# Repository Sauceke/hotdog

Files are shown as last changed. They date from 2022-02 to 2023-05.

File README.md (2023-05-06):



# Hotdog

*A pocket pussy with depth sensing.*

<br>

<div align = center>

---

[][Demo]   
[][Firmware]   
[][PCB & Case]

---

</div>

<br>
<br>

## Assembly

*How to build this project.*

[][Wireless]   
[][Wired]

<br>
<br>

## Acknowledgment

Thanks to **[@ManlyMarco]** for the idea.

<br>

<!----------------------------------------------------------------------------->

[@ManlyMarco]: https://github.com/ManlyMarco
[Demo]: https://www.erome.com/a/rvRyi8gS

[License]: LICENSE
[PCB & Case]: https://github.com/Sauceke/hotdog/tree/master/Source/Hardware
[Firmware]: https://github.com/Sauceke/hotdog/tree/master/Source/Firmware
[Wireless]: Documentation/Wireless.md
[Wired]: Documentation/Wired.md

<!---------------------------------[ Badges ]---------------------------------->

[Badge License]: https://img.shields.io/badge/License-GPL_3-blue.svg?style=for-the-badge

<!--------------------------------[ Buttons ]---------------------------------->

[Button PCB & Case]: https://img.shields.io/badge/PCB_&_Case-3863A0?style=for-the-badge&logoColor=white&logo=Task
[Button Firmware]: https://img.shields.io/badge/Firmware-00979D?style=for-the-badge&logoColor=white&logo=Arduino
[Button Wireless]: https://img.shields.io/badge/Wireless-006643?style=for-the-badge&logoColor=white&logo=RSS
[Button Wired]: https://img.shields.io/badge/Wired-2D50A5?style=for-the-badge&logoColor=white&logo=EquinixMetal
[Button Demo]: https://img.shields.io/badge/NSFW_Demo-ED2761?style=for-the-badge&logoColor=white&logo=Aparat

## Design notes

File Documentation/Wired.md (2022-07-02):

# Wired Assembly

*How to build a cheap **Hotdog**.*

<br>

If you have access to a 3D printer and use a cheap  
Nano clone with `CH340`, the whole thing will run  
you around `$20`, not counting the sleeve itself.

<br>

## Parts

-   Transparent Sleeve

    *I use **[This][Sleeve]** one.*

-   3D Printed

    - **[Bottom Casing]**
    - **[Top Casing]**
    
    <br>
    
-   Arduino Nano

-   2 x Single row 15 pin female header

-   2 x Universal PCB 

    `50mm x 100mm`
    
    Such as:
    
    - **[Amazon][PCB Amazon]**
    - **[Hestore][PCB Hestore]**
    - **[Ormix][PCB Ormix]**
    
    <br>
    
-   5 x `GL5528` Photoresistor

-   3 x `334-15/T1C1-4WYA` LEDs 
    
    *These are actually overkill, you could also*  
    *go with dimmer LEDs and a smaller resistor*
    
-   `1kΩ` resistor

-   Long USB cable 

    *For the Arduino Nano*

-   Mini zip ties

    *Less than `3mm` in width*
    
-   Rubber bands

-   Solder and hook-up wire

<br>
<br>

## Programming

Upload the **[Firmware]** to the micro-controller.

*Check out the **[Guide]** if you have never done this.*

<br>
<br>

## Assembly

1.  Place the photo-resistors on the **back side** of the  
    PCB at equal distances along the middle line.

    The exact distance between them is not that  
    important, but try to place them evenly.
    
    Solder them in position.
    
    *This is easier if your PCB is plated on both sides, if it  
    isn't, then take extra care not to burn the photocells.*

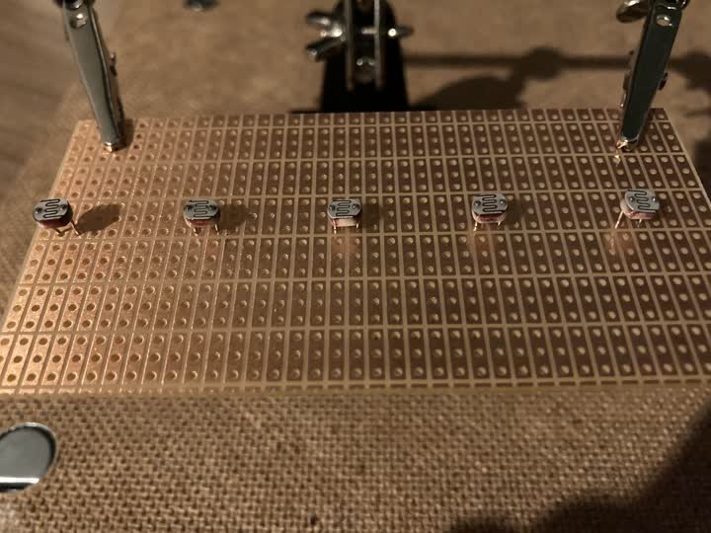
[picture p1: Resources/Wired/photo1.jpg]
    
    
    <br>

2.  Wire up the photocells as shown diagram, except  
    with the wires on the **front side** of the board.
    
    

    The front side should look something like this:
    
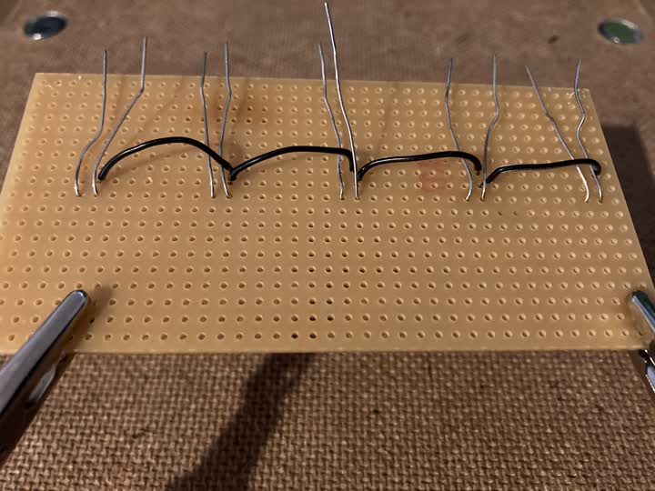
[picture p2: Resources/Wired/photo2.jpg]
    
    
    <br>

3.  Put the sockets on the Nano and solder them  
    onto the board in the below orientation.

    *Leave at least one row space at the top ↓*

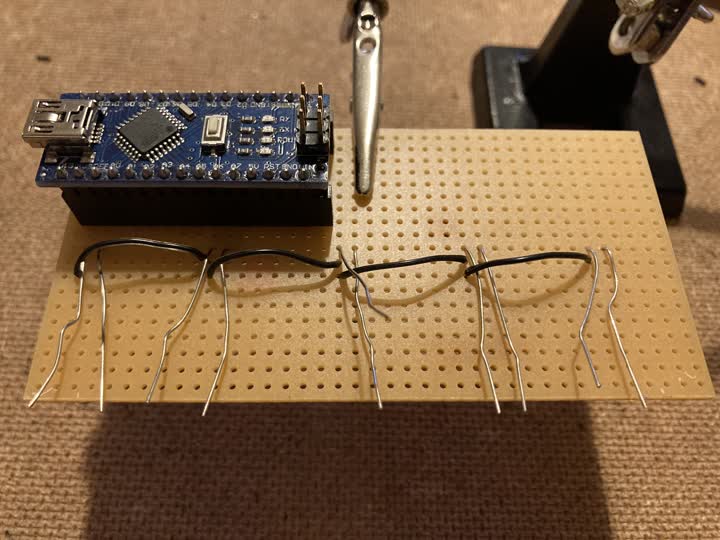
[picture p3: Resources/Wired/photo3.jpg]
    

    You don't have to solder each and every pin  
    in, but at the bare minimum, do the corners.
    
    Make sure you don't solder any adjacent pins together.
    
    <br>

4.  Now connect the photocells to the  
    Nano according to the diagram.

    ***Do NOT solder the wires directly onto***  
    ***the Nano, solder them to the sockets.***
    
    *I couldn't find a way to illustrate this in*  
    *Fritzing, so also see the photo for reference.*

    
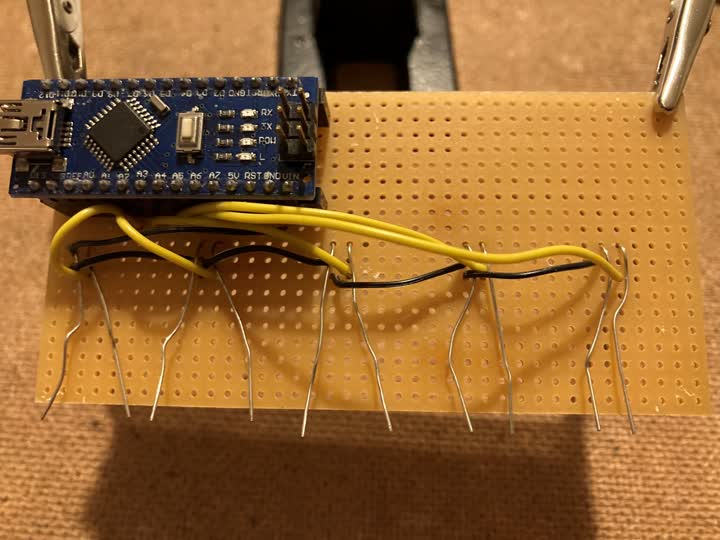
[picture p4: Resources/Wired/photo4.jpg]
    

    After the photocells are connected, you can trim off all the legs.
    
    <br>

5.  Mount the LEDs on the second PCB and  
hook them up to the Nano to each other.
    
    *Black wire to cathodes.*

    Don't forget the resistor.
    
    
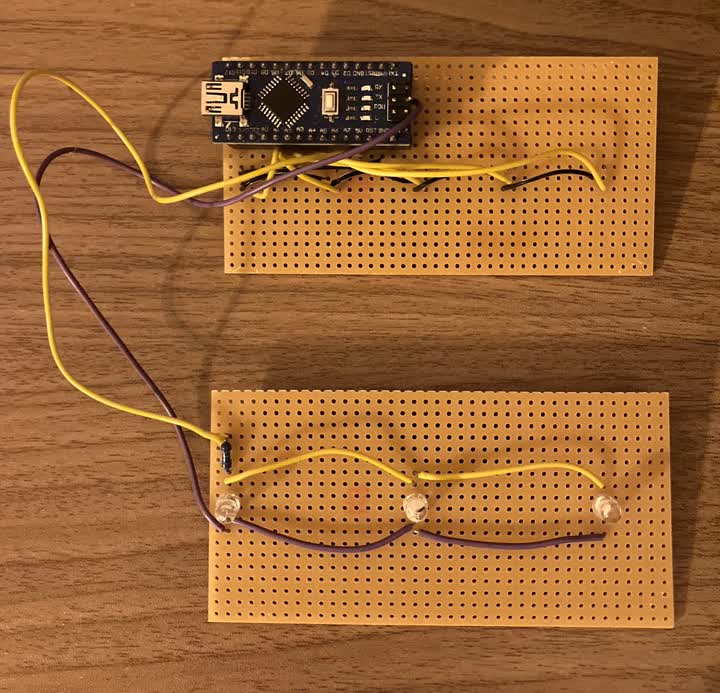
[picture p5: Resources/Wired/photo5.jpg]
    

    <br>

6.  Tie the casings together at the back with zip-ties.

    Leave them loose and don't tighten them until the sleeve is in.

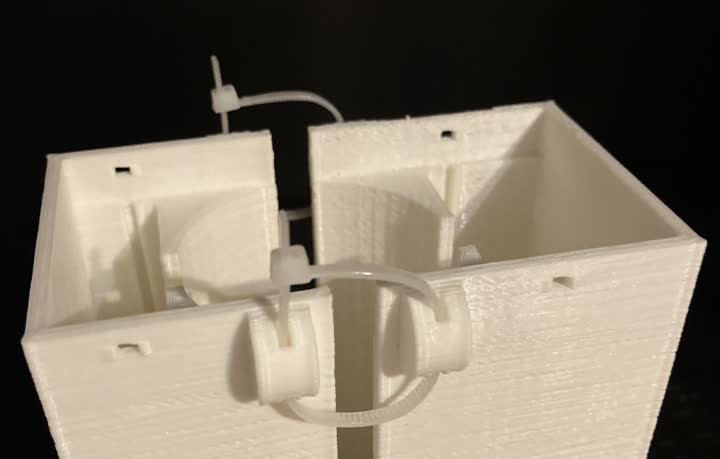
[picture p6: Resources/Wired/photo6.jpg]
    

    <br>

7.  Slide the PCBs in, secure each with a zip-tie  
    and the clipped off end of another zip-tie.
    
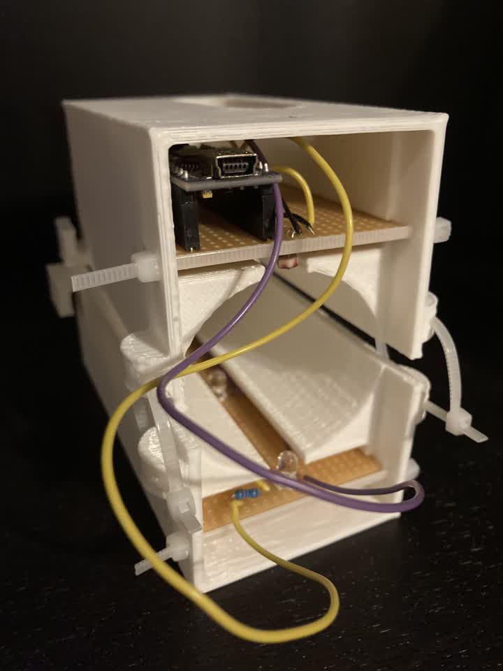
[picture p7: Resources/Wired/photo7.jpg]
    
    
    <br>

8.  Add the sleeve, hold it down with rubber bands  
    at the front and tighten the zip-ties at the back.

    *Make sure all sides of the casing press down on the sleeve evenly.*

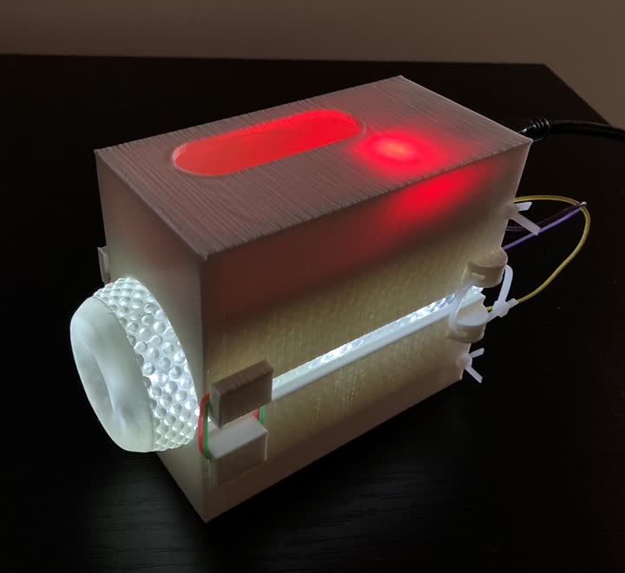
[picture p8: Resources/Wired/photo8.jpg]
    

    <br>

9.  Serve hot.

<br>

<!----------------------------------------------------------------------------->

[Firmware]: https://github.com/Sauceke/hotdog/releases/latest/download/hotdog-fw.ino

[Guide]: https://docs.arduino.cc/software/ide-v1/tutorials/getting-started/cores/arduino-avr

<!---------------------------------[ Parts ]----------------------------------->

[Sleeve]: https://www.thehandy.com/product/the-handy-open-ended-sleeve-collection-hard-eu-uk-2/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

[Bottom Casing]: https://github.com/Sauceke/hotdog/releases/latest/download/hotdog-case-bottom.stl
[Top Casing]: https://github.com/Sauceke/hotdog/releases/latest/download/hotdog-case-top.stl

[PCB Hestore]: https://www.hestore.hu/prod_10031793.html?lang=en
[PCB Amazon]: https://www.amazon.de/-/en/WITTKOWARE-Perforated-Compartments-Copper-RM2-54/dp/B07W8H39TR
[PCB Ormix]: https://ormix.lv/en/catalog/item/id/21692/

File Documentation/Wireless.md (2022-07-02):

# Wireless Assembly

*How to build an **IOT Hotdog**.*

<br>

## Parts list

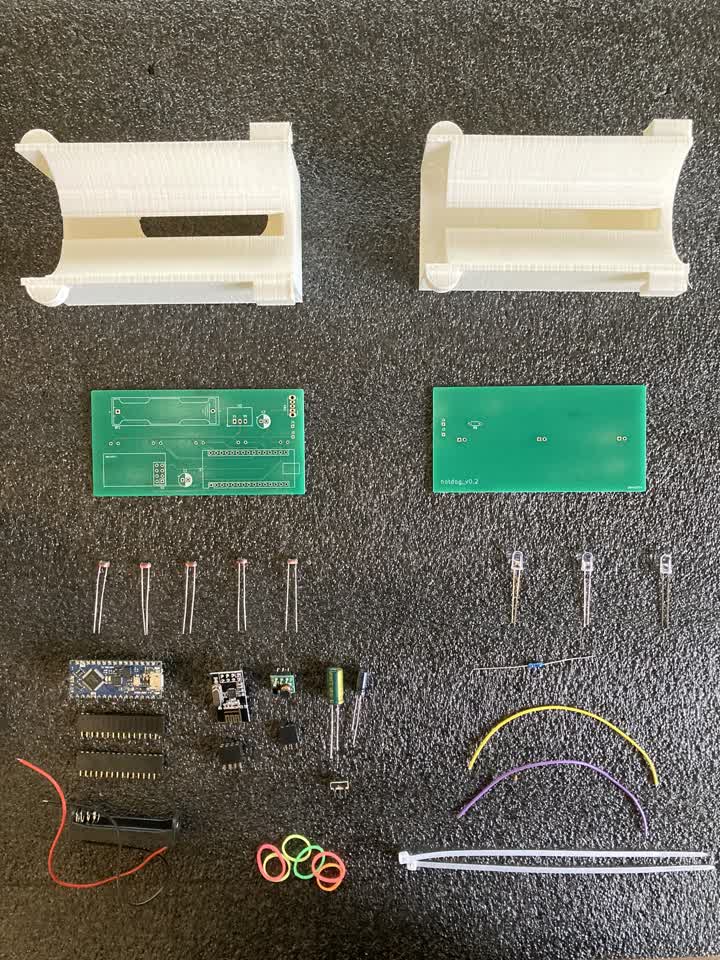
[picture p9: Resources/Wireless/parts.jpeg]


<br>

### Custom Parts

#### 3D Print

- **[Top Casing]**

- **[Bottom Casing]**

<br>

#### Order PCBs

Estimated Cost : `10 - 20 US$` per PCB

- **[Front PCB]**

- **[Back PCB]**

###### Specifications:

- Solder Mask : `Yes`
- Thickness : `1.6mm`
- Layers: `2`
- Size : `100 x 50 mm`
- HASL : `Yes`

<br>

### Stock Parts

- **`A1` : Arduino Nano or compatible + two `1x15` pin female headers**

- `BT1` : AAA battery holder (thru-hole mount recommended)

- `C1` : `10 - 100uF` capacitor (optional)

- `C2` : `~1000uF` capacitor (optional)

- **`D1-D3` : three white LEDs, I used `334-15` / `T1C1-4WYA`**

- **`12cm` long hook-up wire connecting `J1` to `J4`**

- **`12cm` long hook-up wire connecting `J2` to `J3`**

- **`R1-R5` : five GL5528 photoresistors**

- **`R6` : 1kΩ resistor (or lower if you're using less bright LEDs)**

- `SW1` : **SPDT** switch

- `U1` : `nRF24L01` + a `2x4` pin female header

- `U2` : `0.8 - 5V` to `5V` boost converter + a `1x3` pin female header

- A transparent sleeve, I used **[This][Sleeve]** one.

- Mini zip ties

- Rubber bands

<br>
<br>

## Programming

### Arduino Nano

Extract this **[Zip]** file and upload  
the file `hotdog-fw.ino.hex` to  
the Nano using **[XLoader]**.

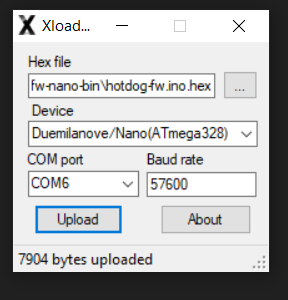
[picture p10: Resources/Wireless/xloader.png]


##### Windows

By default you should be able to  
use `COM0`, if not try other ports.

<br>

### Other 

*Nano-compatible microcontrollers*

Compile & upload the **[Firmware]** using the **[Arduino IDE]**.

##### Dependencies

- **Protothreads**
- **BTLE**
- **RF24**

<br>
<br>

## Assembly

### Soldering Font PCB

1.  Place the `1x15` headers on the Nano.

    *I didn't have 1x15, so I cheated and yanked*  
    *out one of the terminals from a `1x16`.*
    
    *Don't be like me.*

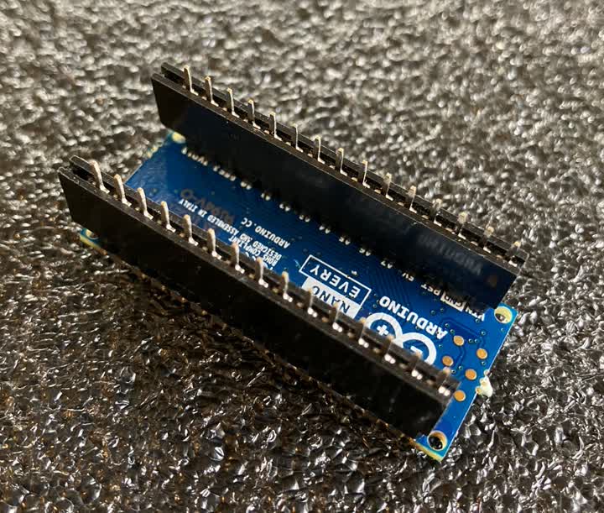
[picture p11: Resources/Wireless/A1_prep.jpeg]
    
    
    <br>

2.  Solder the micro-controller to the PCB with  
    its USB connector facing towards the edge.

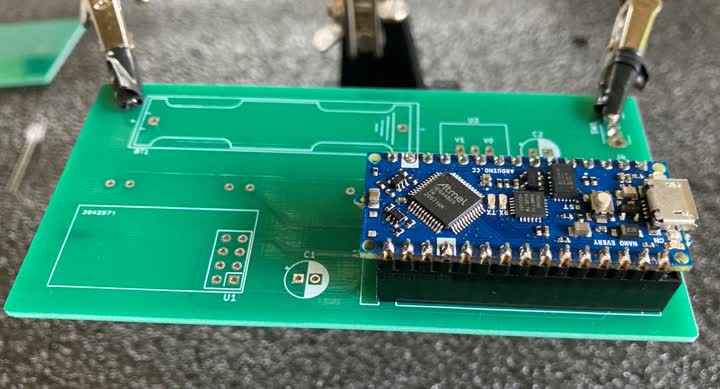
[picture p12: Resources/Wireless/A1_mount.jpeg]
    
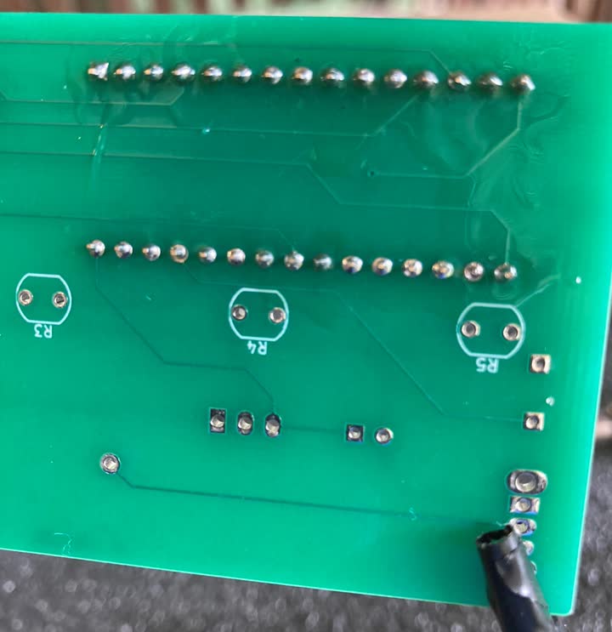
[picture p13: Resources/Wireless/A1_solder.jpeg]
    
    
    <br>

3.  Solder the photo-resistors to `R1-R5`  
    on the opposite side of the PCB.

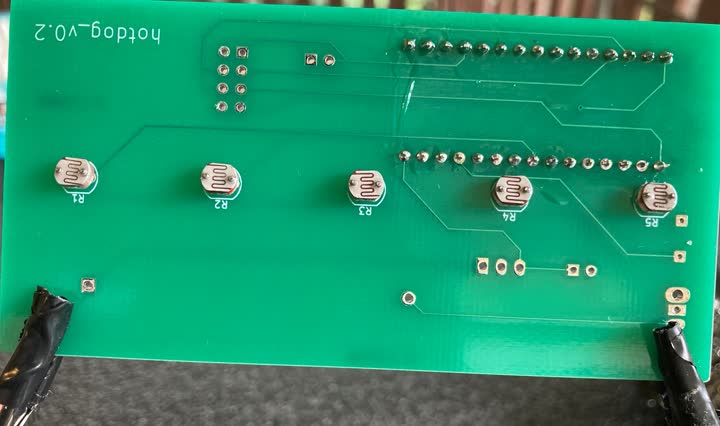
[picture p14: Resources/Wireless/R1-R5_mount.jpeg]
    

    <br>

    *It is recommended to clip the leads off*  
    *before soldering to minimize heat loss.*
    
    I prefer to also bend the wires in before clipping  
    them short, so the parts won't come loose.

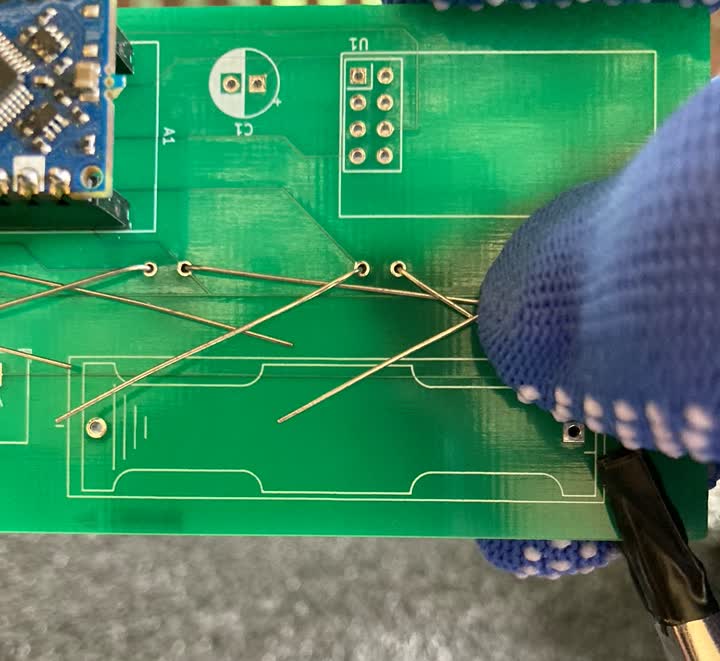
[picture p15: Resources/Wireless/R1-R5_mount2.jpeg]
    
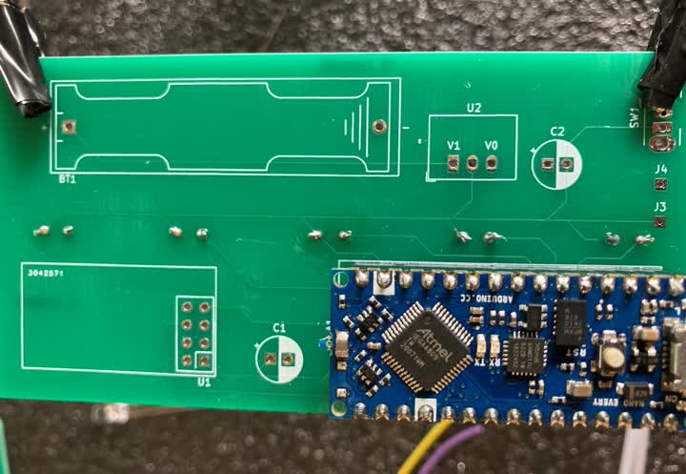
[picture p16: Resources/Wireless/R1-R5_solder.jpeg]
    
    
    <br>

4.  Solder the `2x4` header to `U1`.

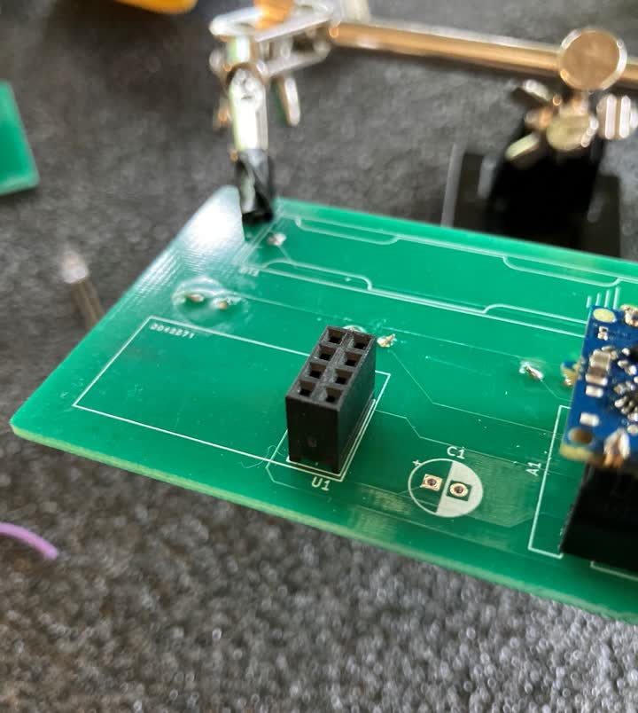
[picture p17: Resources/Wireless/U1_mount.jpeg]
    
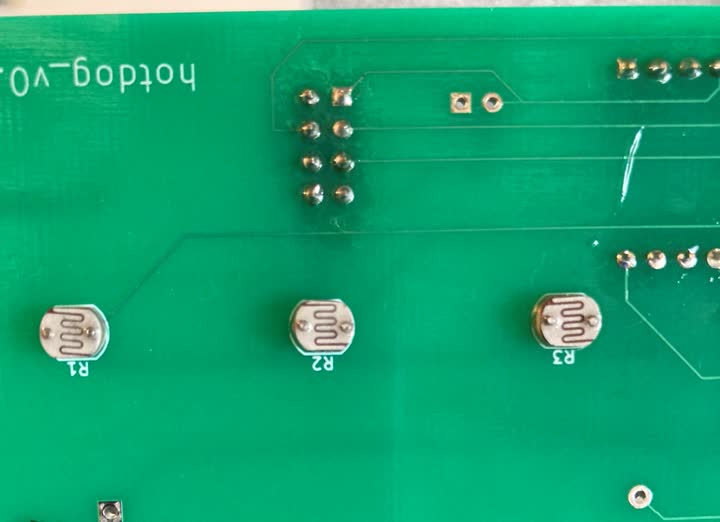
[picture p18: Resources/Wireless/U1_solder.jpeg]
    
    
    <br>

5.  Put the `1x3` female header on the  
    boost converter and solder it to `U2`.

    Make sure `V1` and `V0` are aligned  
    with the markings on the PCB.

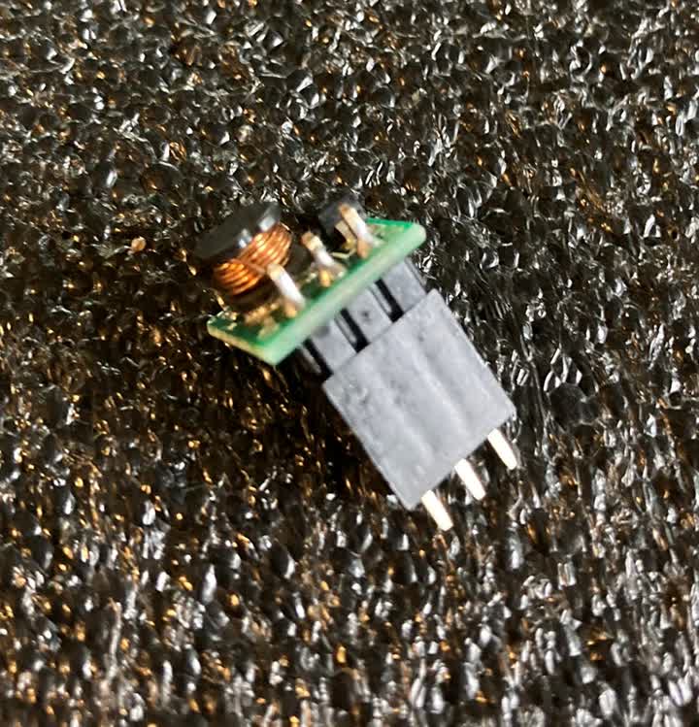
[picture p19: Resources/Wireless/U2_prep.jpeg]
    
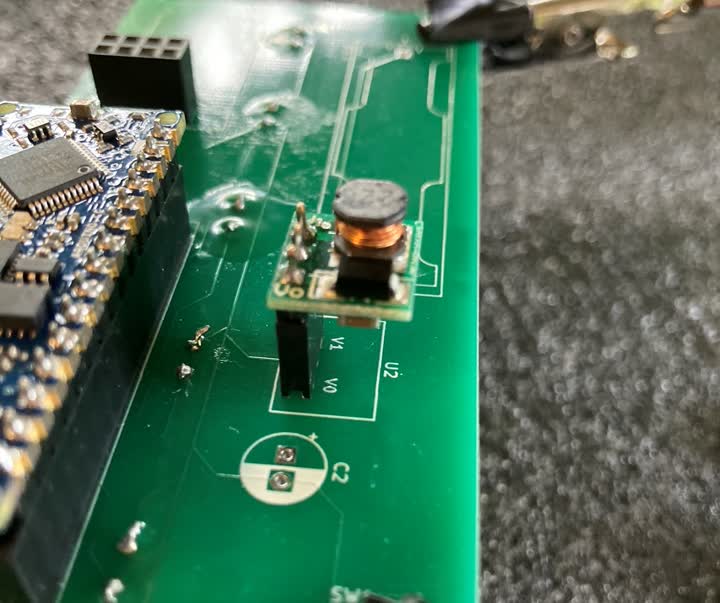
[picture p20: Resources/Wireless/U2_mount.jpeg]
    
    
    <br>

6.  Solder a capacitor of about `1000uF` to `C2`.

    ***Mind the polarity.***

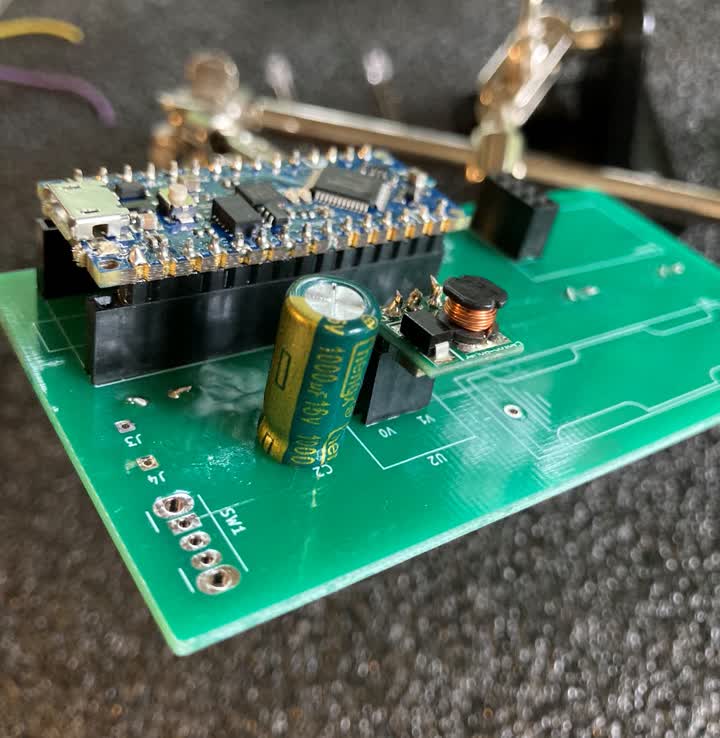
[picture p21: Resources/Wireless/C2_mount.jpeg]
    
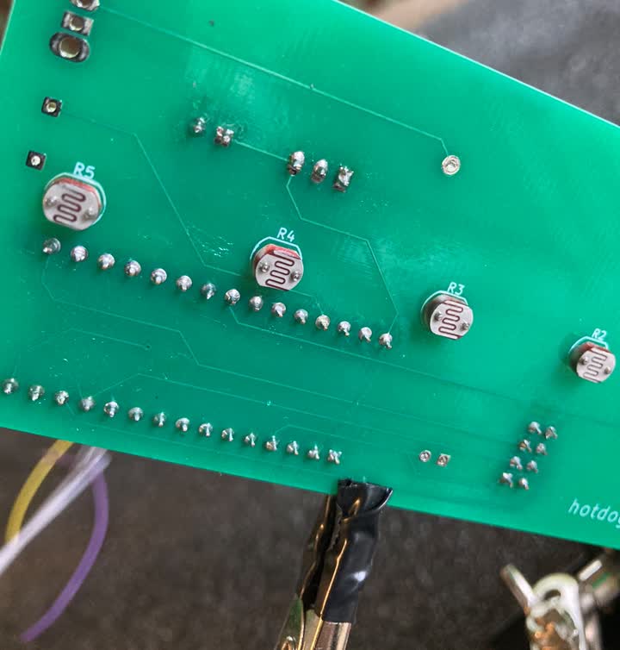
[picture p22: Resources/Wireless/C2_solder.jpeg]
    
    
    <br>

7.  Solder the **SPDT** switch to `SW1`.

    The terminals should go into the three holes in the middle.
    
    Mine was a bit over-sized, but as they  
    say, if there's a hole, there's a way.

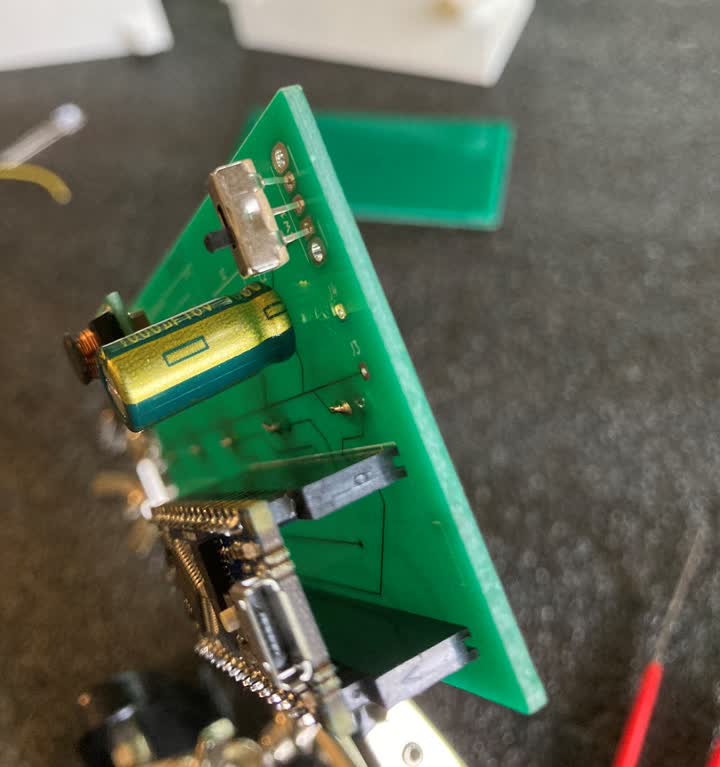
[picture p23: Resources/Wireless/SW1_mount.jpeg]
    
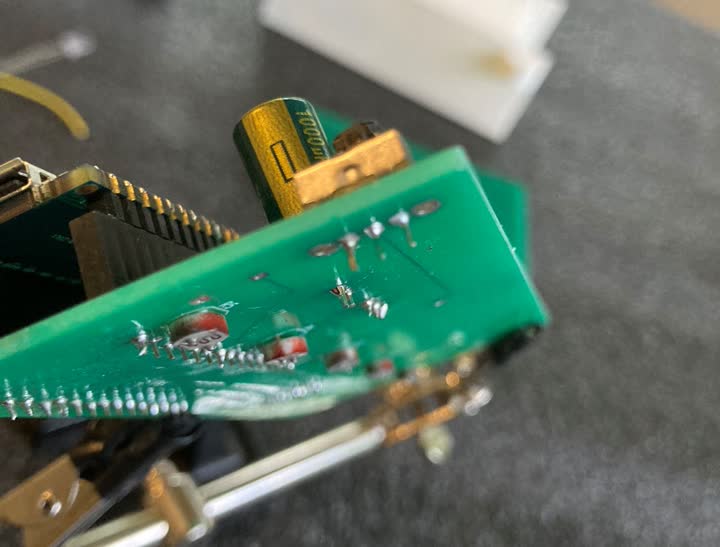
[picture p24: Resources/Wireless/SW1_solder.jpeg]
    

    Words to live by indeed.
    
    <br>

8.  If you have a thru-hole mount `1xAAA` battery  
    holder, you can go ahead and solder it to `BT1`  
    and skip to step 13.

    ***Mind the polarity***

    If you're using a cheaper battery holder like  
    I did, we need to take a few extra steps.
    
    This can get quite messy though, so in  
    retrospect I absolutely recommend  
    getting a proper thru-hole mount.
    
    <br>

9.  First, trim both wires to about `2cm`, and put some  
    deep scratches into the bottom with a sharp object.

    This is crucial to ensure proper adhesion  
    to the board, so carve it up like a psycho.

    
    
    <br>

10. Then solder it to `BT1` in the correct polarity.

    
    
    <br>

11. Clean both the `BT1` footprint and the  
    battery holder with isopropyl alcohol.

12. Glue the battery holder to `BT1` with epoxy.

    ***⚠ Make sure there is at least `5mm` clearance***  
    ***between the battery holder and the edge of***  
    ***the motherboard.***
    
    *It doesn't have to be precisely on the footprint,*  
    *but do not place it any further below that.*

    
    

    Clamp it down and wait for the glue to dry.
    
    Meanwhile, you can start assembling the [Back PCB](#soldering-back-pcb).
    
    <br>

13. Solder a 100uF capacitor to `C1`.

    ***Mind the polarity.***

    
    
    <br>

14. Insert the `nRF24` into the `U1` socket,  
    and that's the front motherboard done.

    
    

<br>
<br>

### Soldering Back PCB

1.  Solder the LEDs to `D1-D3`.

    Pay attention to polarity; one of the sides  
    on each LED is flattened, line that up with  
    the drawing on the PCB.
      
    
    
    
    <br>
  
2.  Solder a `1K` resistor to `R6`.

    
    
    <br>

3.  Connect `J1` to `J4` and `J2` to `J3`  
    with `12cm` long hook-up wires.

    Solder those in as well.

    

    The motherboards are now complete.

    

<br>
<br>

### Final Assembly

1.  Slide the PCB into the casing:

    **Front PCB**  ➞  **Top Casing**

    **Bottom PCB**  ➞  **Bottom Casing**

    *Make sure the LEDs and the photo-resistors*  
    *all face inwards, where the sleeve will be.*

2.  Secure each PCB with a zip tie and  
    the cut-off end of another zip tie.

3.  Add the sleeve.

4.  Use zip ties to bind the two casing  
    parts at their open ends together.

    Fasten the zip ties just tight enough that  
    the casing won't separate from the sleeve.

5.  Secure the other end of the casing  
    to the sleeve with rubber bands.

6.  Insert the battery, power it on and serve.

<br>
<br>

## Operation

In wireless mode, the **Hotdog** is powered by a single  
AAA battery that should last you about `2 - 3` hours  
on a single charge.

*I recommend using a rechargeable one.*

*There's no battery level indicator, so recharge frequently.*

I'm still working on the client app for  
wireless, but it's already looking great.

Stay tuned!

<br>

<!----------------------------------------------------------------------------->

[Firmware]: https://github.com/Sauceke/hotdog/releases/latest/download/hotdog-fw.ino
[Zip]: https://github.com/Sauceke/hotdog/releases/latest/download/hotdog-fw-nano-bin.zip

[Arduino IDE]: https://www.arduino.cc/en/software
[XLoader]: https://www.hobbytronics.co.uk/arduino-xloader

<!---------------------------------[ Parts ]----------------------------------->

[Bottom Casing]: https://github.com/Sauceke/hotdog/releases/latest/download/hotdog-case-bottom.stl
[Top Casing]: https://github.com/Sauceke/hotdog/releases/latest/download/hotdog-case-top.stl

[Front PCB]: https://github.com/Sauceke/hotdog/releases/latest/download/hotdog-pcb-front-fab.zip
[Back PCB]: https://github.com/Sauceke/hotdog/releases/latest/download/hotdog-pcb-back-fab.zip

[Sleeve]: https://www.thehandy.com/product/the-handy-open-ended-sleeve-collection-hard-eu-uk-2/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

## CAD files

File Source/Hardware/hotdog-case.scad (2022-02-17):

$fn = 50;

t = 0.7; // tolerance
pcb = [50 + t, 1.5 + t, 100 + t];

big = 420; // arbitrary big value

module pcb_clearance(h_top) {
    h_bottom = 5;
    h_slit = 30;
    w_slit = 10;
    margin = 4;
    cube(pcb, center = true);
    translate([0, -h_top / 2, 0])
        cube([pcb[0] - margin, h_top, pcb[2] - margin], center = true);
    translate([0, h_bottom / 2, 0])
        cube([pcb[0] - margin, h_bottom, pcb[2] - margin], center = true);
    translate([0, h_slit / 2, 0])
        cube([w_slit, h_slit, pcb[2]], center = true);
    translate([0, -h_top / 2, pcb[2] / 2])
        cube([pcb[0], h_top, 10], center = true);
    translate([0, big / 2, pcb[2] / 2])
        cube([pcb[0], big, 10], center = true);
    translate([0, 0, pcb[2] / 2 + 1])
        cube([big, 3, 2], center = true);
}

module sleeve_clearance() {
    sleeve_d = 50;
    translate([0, 32, 0])
    cylinder(d = sleeve_d, h = pcb[2] + 20, center = true);
}

module ear() {
    ear_h = 15;
    intersection() {
        difference() {
            cube([8, 8, ear_h], center = true);
            cube([3, 2, ear_h], center = true);
        }
        translate([4, 0, 0])
            rotate([90, 0, 0])
                cylinder(d = ear_h, h = 100, center = true);
    }
}

module hook() {
    ear_h = 16;
        difference() {
            cube([8, 12, ear_h], center = true);
            translate([2, -2, 0])
                cube([4, 8, big], center = true);
        }
}

module case(h_top, battery_hole) {
    difference() {
        translate([0, (25 - h_top) / 2, 0])
            cube([pcb[0] + 5, 30 + h_top, pcb[2] + 10], center = true);
        pcb_clearance(h_top);
        sleeve_clearance();
        if (battery_hole) {
            hull() {
                rotate([90, 0, 0]) {
                    translate([-10, -pcb[2] / 2 + 20, 0])
                        cylinder(d = 20, h = big);
                    translate([-10, 10, 0])
                        cylinder(d = 20, h = big);
                }
            }
        }
    }
    corner = [- pcb[0] / 2 - 6, 20, pcb[2] / 2 - 3];
    module ear_corner() {
        translate(corner)
            ear();
    }
    module hook_corner() {
        translate(corner)
            hook();
    }
    ear_corner();
    mirror([1, 0, 0])
        ear_corner();
    mirror([0, 0, 1])
        hook_corner();
    mirror([1, 0, 0])
        mirror([0, 0, 1])
            hook_corner();
}

module hotdog_bottom() {
    case(10, false);
}

module hotdog_top() {
    case(20, true);
}

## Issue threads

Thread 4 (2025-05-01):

help wanted:How to debug and calibrate the device?

imfrea, 2025-05-01:
I am following up on the closed issue [original issue link](https://github.com/Sauceke/hotdog/issues/1#issuecomment-2844808915).

How can I verify if the device is functioning correctly? When I cover half or all of the photoresistor, the serial output only shows "L020" continuously. With no obstruction, it consistently outputs "L0100".

Could you provide guidance on debugging and calibrating the device to resolve this behavior?

Thank you for your support!

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

Sauceke, 2025-05-04:
Does it do the same when the ona is inside? The LEDs are basically point light sources, something has to diffuse the light. It will only measure meaningful values with a translucent sleeve in between.

imfrea, 2025-05-05:
> Does it do the same when the ona is inside? The LEDs are basically point light sources, something has to diffuse the light. It will only measure meaningful values with a translucent sleeve in between.

Sorry, I identified the cause – I had soldered the photoresistors in reverse order. Specifically, the actual R1 was connected to the A0 pin. After correcting the order, the sensor values now linearly transition between 100 and 0 as expected.

However, synchronization with the game remains problematic:

When both the "KKS_LoveMachine" plugin and the "KKS_LoveMachine.Experiments" plugin are installed, the game connects to Intiface Centre instead of the Hotdog Server on startup.

If only "KKS_LoveMachine.Experiments" is installed, the game successfully connects to the Hotdog Server. Here is the relevant log:
`Hotdog server running on port 5365.`
`Client connected`
`Listening to Hotdog serial device on port COM12`
This may seem normal, but the action synchronization in the H scene is not normal. After selecting a position, the game will automatically insert and remove once, and then the pleasure of male and female characters will continue to rise until the orgasm animation is automatically played. No matter how the sensors are obstructed during this period, there is no corresponding change in the game.

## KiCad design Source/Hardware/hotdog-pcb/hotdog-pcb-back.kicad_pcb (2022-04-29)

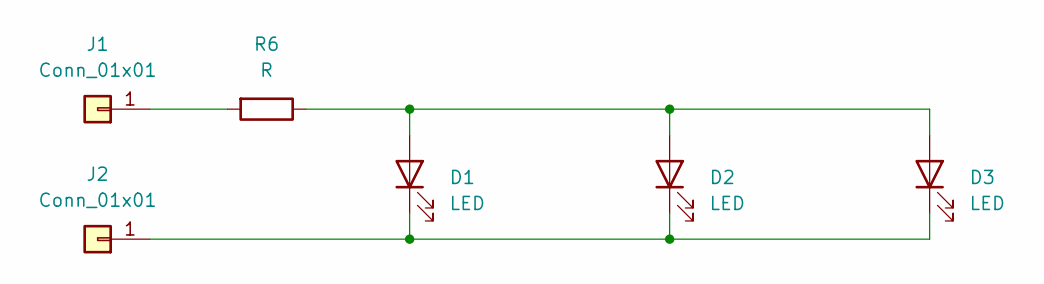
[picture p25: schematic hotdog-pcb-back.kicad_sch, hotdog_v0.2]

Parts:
D1, D2, D3: LED; LED_D5.0mm
J1, J2: Conn_01x01; SolderWire-0.1sqmm_1x01_D0.4mm_OD1mm
R6: R; R_Axial_DIN0204_L3.6mm_D1.6mm_P5.08mm_Horizontal

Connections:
unnamed: D1.1 (K), D2.1 (K), D3.1 (K), J2.1
unnamed: D1.2 (A), D2.2 (A), D3.2 (A), R6.1
unnamed: J1.1, R6.2

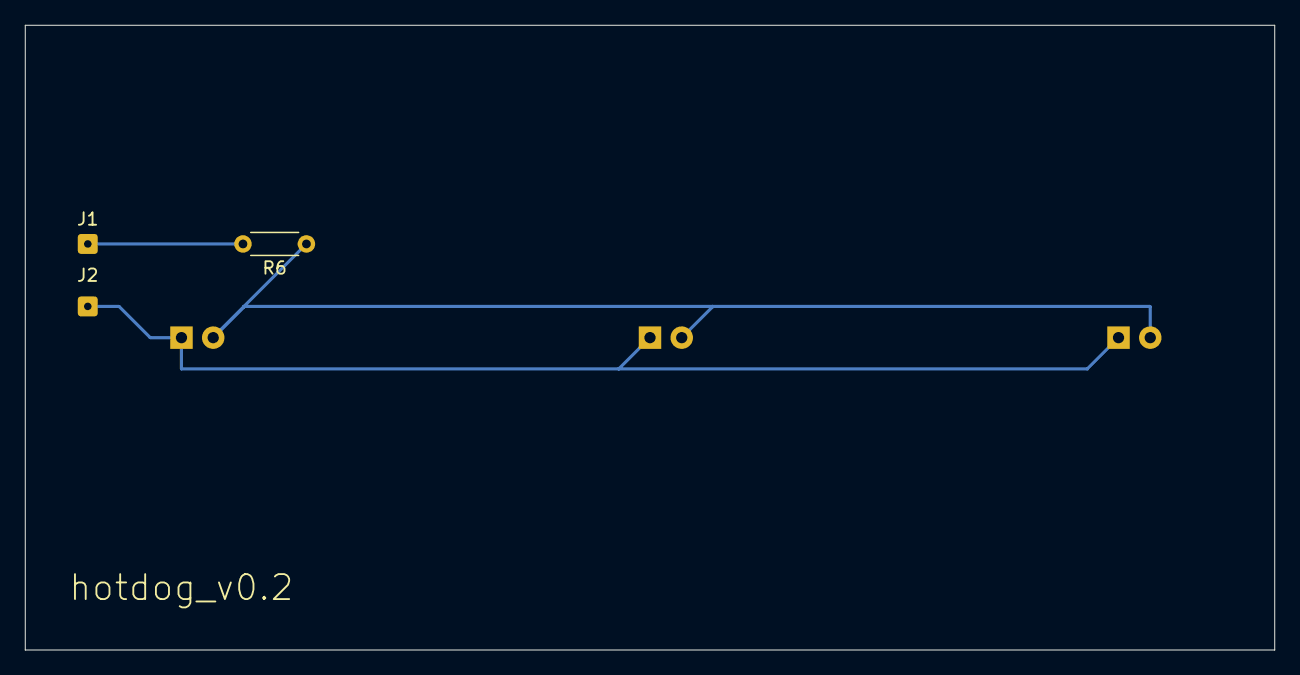
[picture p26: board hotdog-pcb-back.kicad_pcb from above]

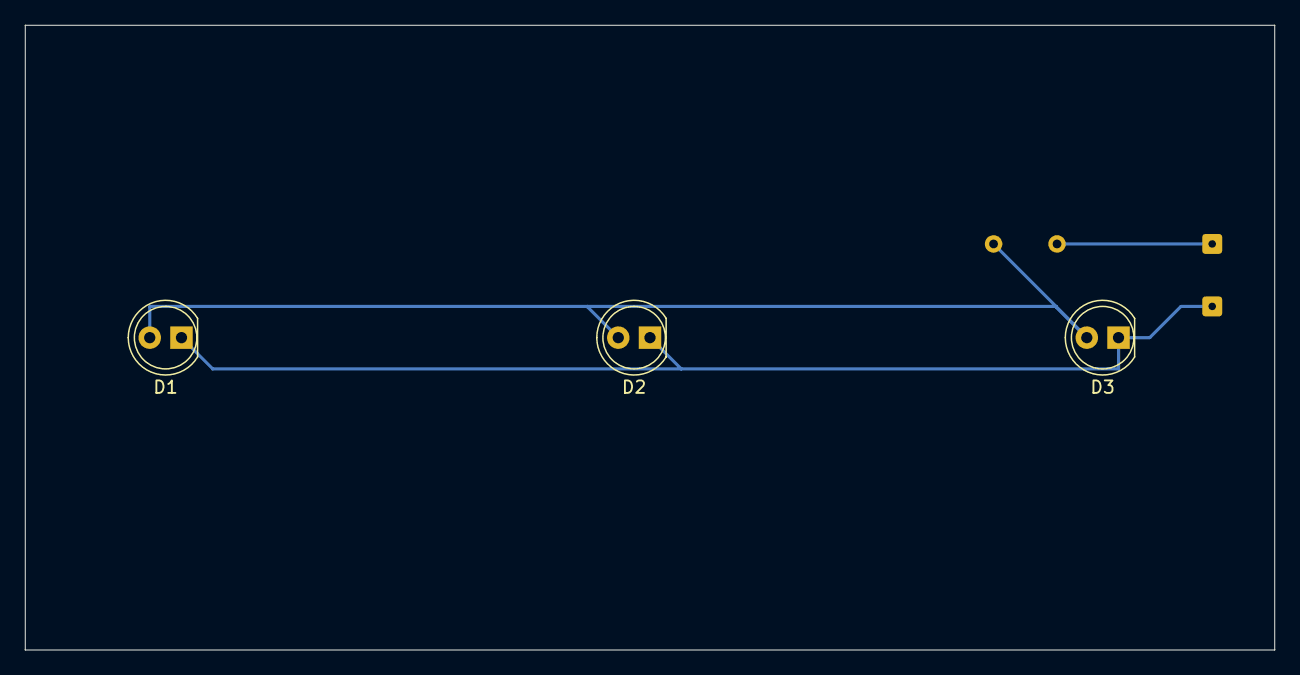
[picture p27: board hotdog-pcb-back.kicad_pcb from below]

Board: 2 copper layers, 100.0 x 50.0 mm, 6 parts (3 on the bottom side), 3 nets.

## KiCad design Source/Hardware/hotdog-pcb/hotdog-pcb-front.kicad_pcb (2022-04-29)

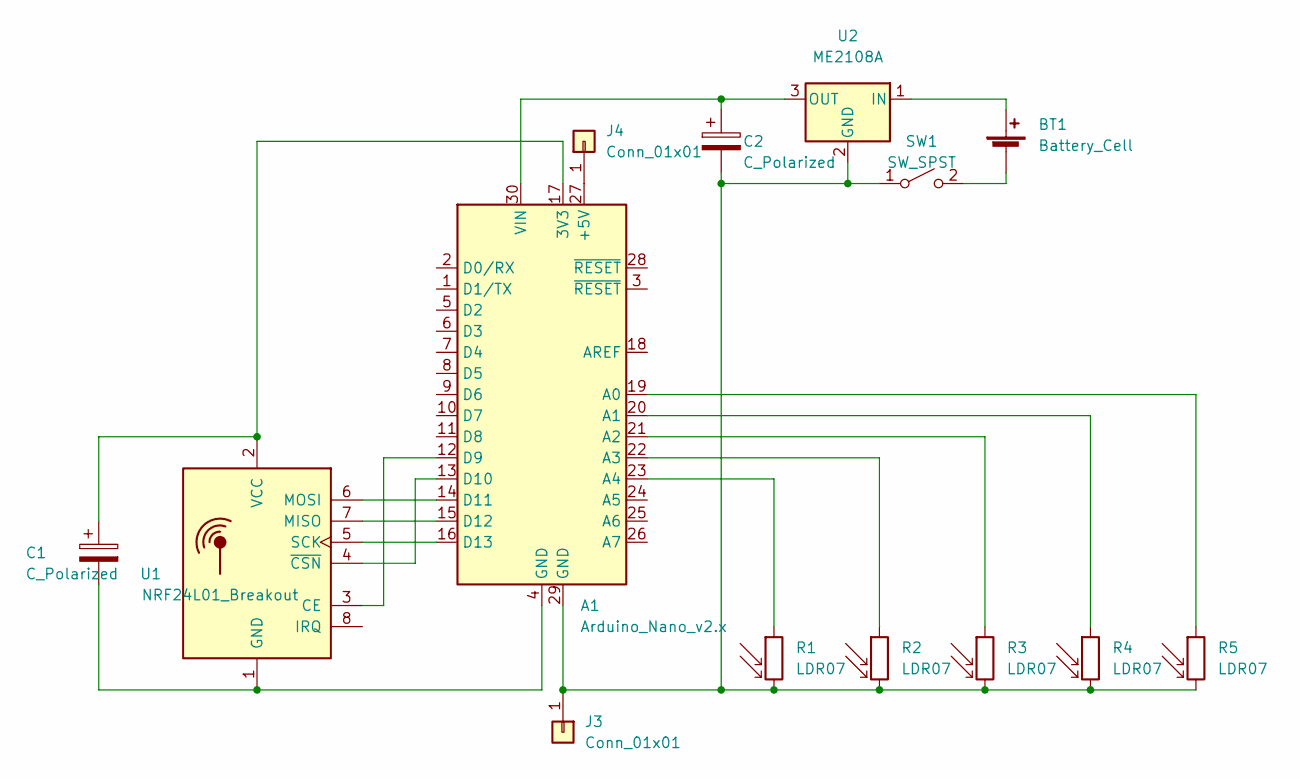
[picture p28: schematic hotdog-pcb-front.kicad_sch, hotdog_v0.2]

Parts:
A1: Arduino_Nano_v2.x; Arduino_Nano
BT1: Battery_Cell; BatteryHolder_Keystone_2466_1xAAA
C1, C2: C_Polarized; CP_Radial_D6.3mm_P2.50mm
J3, J4: Conn_01x01; SolderWire-0.1sqmm_1x01_D0.4mm_OD1mm
R1, R2, R3, R4, R5: LDR07; R_LDR_5.1x4.3mm_P3.4mm_Vertical
SW1: SW_SPST; SW_CuK_OS102011MA1QN1_SPDT_Angled
U1: NRF24L01_Breakout; nRF24L01_Breakout
U2: ME2108A; Converter_DCDC_RECOM_R-78E-0.5_THT

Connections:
unnamed: A1.4 (GND), C1.2, U1.1 (GND)
unnamed: A1.12 (D9), U1.3 (CE)
unnamed: A1.13 (D10), U1.4 (~CSN)
unnamed: A1.14 (D11), U1.6 (MOSI)
unnamed: A1.15 (D12), U1.7 (MISO)
unnamed: A1.16 (D13), U1.5 (SCK)
unnamed: A1.17 (3V3), C1.1, U1.2 (VCC)
unnamed: A1.19 (A0), R5.1
unnamed: A1.20 (A1), R4.1
unnamed: A1.21 (A2), R3.1
unnamed: A1.22 (A3), R2.1
unnamed: A1.23 (A4), R1.1
unnamed: A1.27 (+5V), J4.1
unnamed: A1.29 (GND), C2.2, J3.1, R1.2, R2.2, R3.2, R4.2, R5.2, SW1.1 (A), U2.2 (GND)
unnamed: A1.30 (VIN), C2.1, U2.3 (OUT)
unnamed: BT1.1 (+), U2.1 (IN)
unnamed: BT1.2 (-), SW1.2 (B)

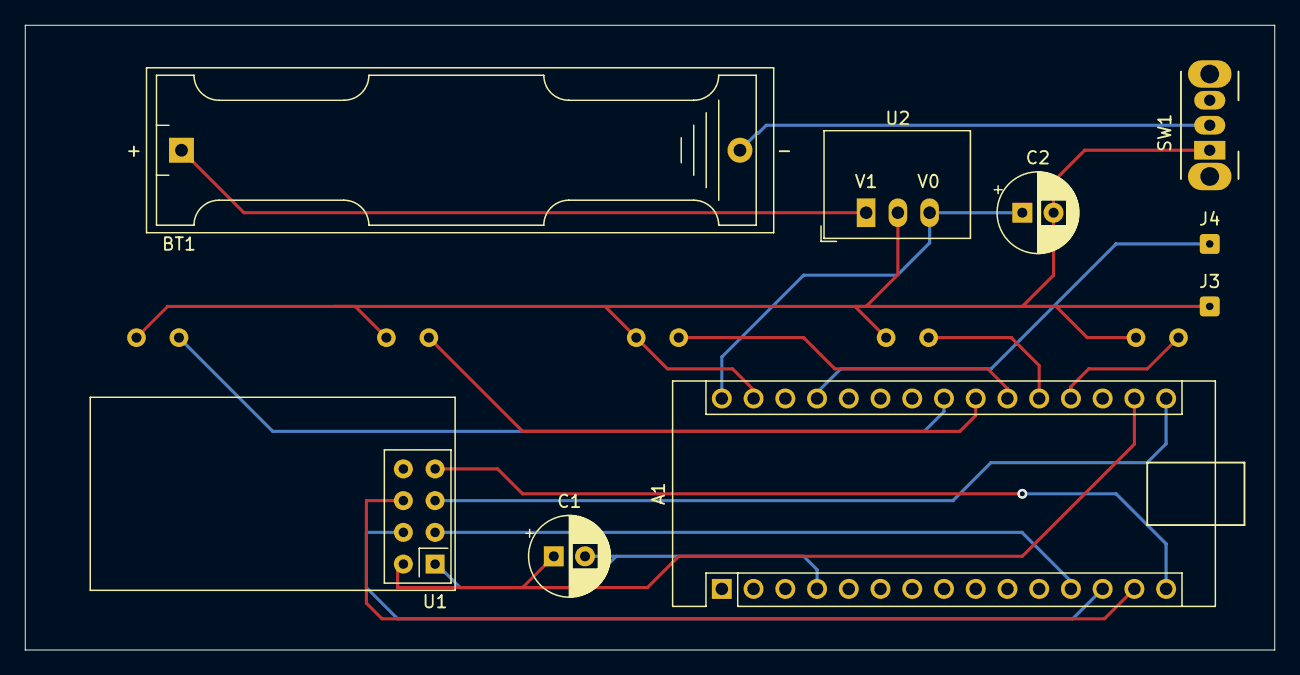
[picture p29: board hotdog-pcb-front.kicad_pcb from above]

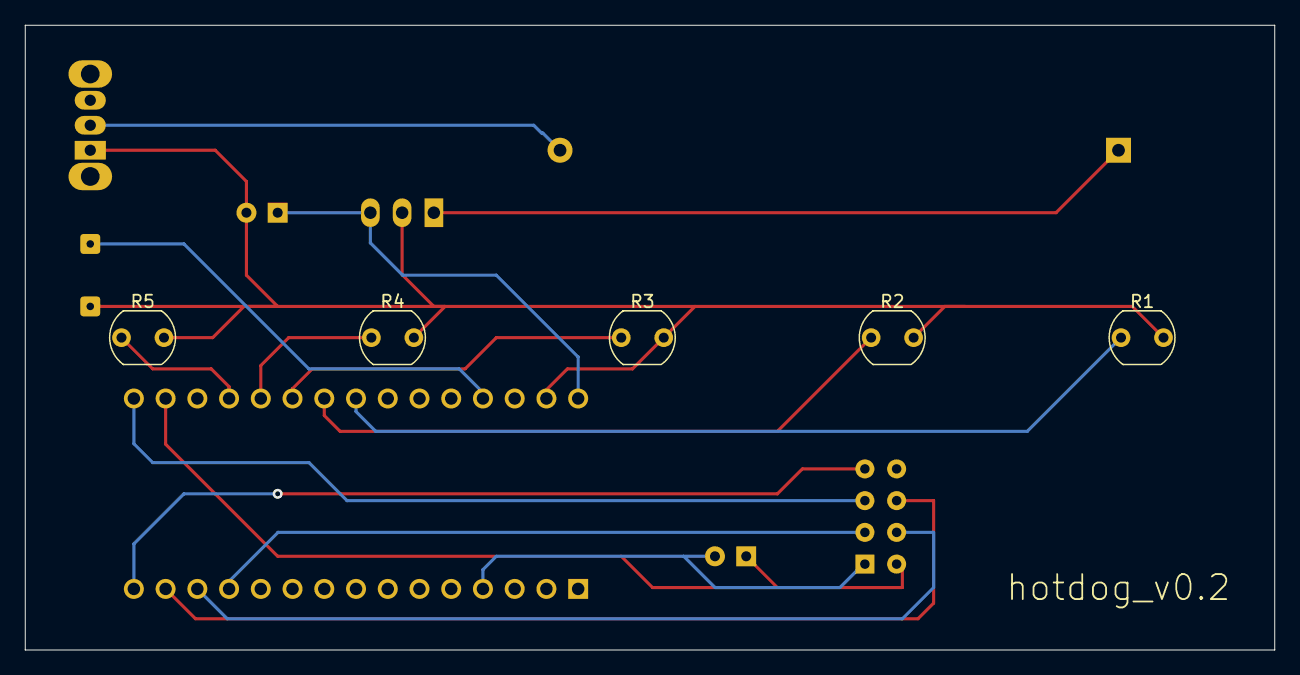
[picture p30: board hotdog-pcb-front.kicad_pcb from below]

Board: 2 copper layers, 100.0 x 50.0 mm, 14 parts (5 on the bottom side), 17 nets.

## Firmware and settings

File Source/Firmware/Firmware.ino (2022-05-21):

#include <SPI.h>
#include <RF24.h>
#include <BTLE.h>
#include <pt.h>

// sensors: A0 to A4
// A0 is the topmost sensor
const int sensors = 5;

// how much the sensor reading has to increase to consider it a shadow
const float threshold = 1.2;

// the sensor readings at calibration
int baseValues[sensors];

struct pt sensorThread, broadcastThread;

RF24 radio(9, 10, 1000000);
BTLE btle(&radio);

int readSensor(int pin) {
  pinMode(pin, INPUT_PULLUP);
  delay(1);
  int value = analogRead(pin);
  pinMode(pin, INPUT);
  return value;
}

void calibrate() {
  // One measurement is no measurement.
  int rounds = 10;
  for (int i = 0; i < sensors; i++) {
    for (int j = 0; j < rounds; j++) {
      baseValues[i] += readSensor(A0 + i);
      delay(10);
    }
    baseValues[i] /= rounds;
  }
}

void setup() {
  Serial.begin(9600);
  delay(1000);
  btle.begin("hotdog");
  radio.setPALevel(RF24_PA_LOW);
  calibrate();
  PT_INIT(&sensorThread);
  PT_INIT(&broadcastThread);
}

void loop() {
  static int level = 0;
  sensorLoop(&sensorThread, &level);
  broadcastLoop(&broadcastThread, &level);
}

void toTcode(char* out, int level) {
  sprintf(out, "L0%d", 100 - level);
}

PT_THREAD(sensorLoop(struct pt* pt, int* level)) {
  PT_BEGIN(pt);
  static float lvl;
  static int i;
  while (true) {
    lvl = 0;
    for (i = 0; i < sensors; i++) {
      PT_YIELD(pt);
      int value = readSensor(A0 + i);
      // stop at the first sensor, from top, that detects a shadow
      if (value > baseValues[i] * threshold) {
        lvl += sensors - i;
        break;
      }
      lvl = (((float)value) / baseValues[i] - 1) / (threshold - 1);
    }
    lvl /= sensors;
    lvl = max(min(lvl, 1), 0);
    *level = int(lvl * 100);
  }
  PT_END(pt);
}

PT_THREAD(broadcastLoop(struct pt* pt, int* level)) {
  PT_BEGIN(pt);
  while (true) {
    char message[10];
    toTcode(message, *level);
    btle.advertise(0x16, &message, strlen(message));
    btle.hopChannel();
    delay(1);
    Serial.println(message);
    PT_YIELD(pt);
  }
  PT_END(pt);
}

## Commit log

2022-02-17 Add circuit diagram
2022-02-17 svg no longer needed, circuitdiagram is FOSS
2022-03-31 Fix stl links
2022-04-26 Add PCB files
    [hotdog-pcb.kicad_pcb, hotdog-pcb.kicad_sch]
2022-04-28 Simplify PCB
    [hotdog-pcb.kicad_pcb, hotdog-pcb.kicad_sch]
2022-04-28 Smooth out a few rough spots in pcb
    [hotdog-pcb.kicad_pcb]
2022-04-29 Learned my lesson about PCB pooling
    [hotdog-pcb-back.kicad_pcb, hotdog-pcb-back.kicad_sch, hotdog-pcb-front.kicad_pcb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]
2022-05-03 Upload images for assembly guide
2022-05-20 Render PCBs in release job
2022-05-20 Add arduino libraries to release job
2022-05-21 remove intermediate kicad outputs
2022-05-21 Fix compatibility with AVR boards
2022-05-21 Wireless version assembly guide
2022-05-22 Add photos and instructions for wireless assembly
2022-07-01 Sorted Files
    [hotdog-case.scad, hotdog-pcb-back.kicad_pcb, hotdog-pcb-back.kicad_sch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]
2022-07-01 Formatted Wired Documentation
2022-07-01 Formatted Most Of Wireless
2022-07-01 Finished Formatting Wireless
2022-07-01 On Request : Moved Assembly Links To README
2022-07-02 On Request : Trailing <br> 🠖 2 x Space
